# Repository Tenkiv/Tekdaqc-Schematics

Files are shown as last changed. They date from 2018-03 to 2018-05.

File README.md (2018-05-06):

# TekdaqcSchematics

pcb file for RevE and RevF are incomplete
- all digital grounds are currently unconnected
#TODO ground plane

RevE contains the files for the current Tekdaqc version

RevF is a modified version of the current Tekdaqc
- GIP15 is moved from PC14 to PH5
- GPI4 is moved from PH0 to PH3
- Digital Output connection has been modified to include a pull down resistor

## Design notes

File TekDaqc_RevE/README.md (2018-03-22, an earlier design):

Folder contains all necessary files to open and make changes to the schematic and pcb files in KiCad

*.pro - project file

*.sch - schematic files

*.lib - contains the components used in the schematic 

*.kicad_pcb - pcb file

*.pretty - contains the files of the footprints used in the pcb file

*.kicad_mod - footprint of the components used in the pcb file

*.net - links the schematic files to the pcb files

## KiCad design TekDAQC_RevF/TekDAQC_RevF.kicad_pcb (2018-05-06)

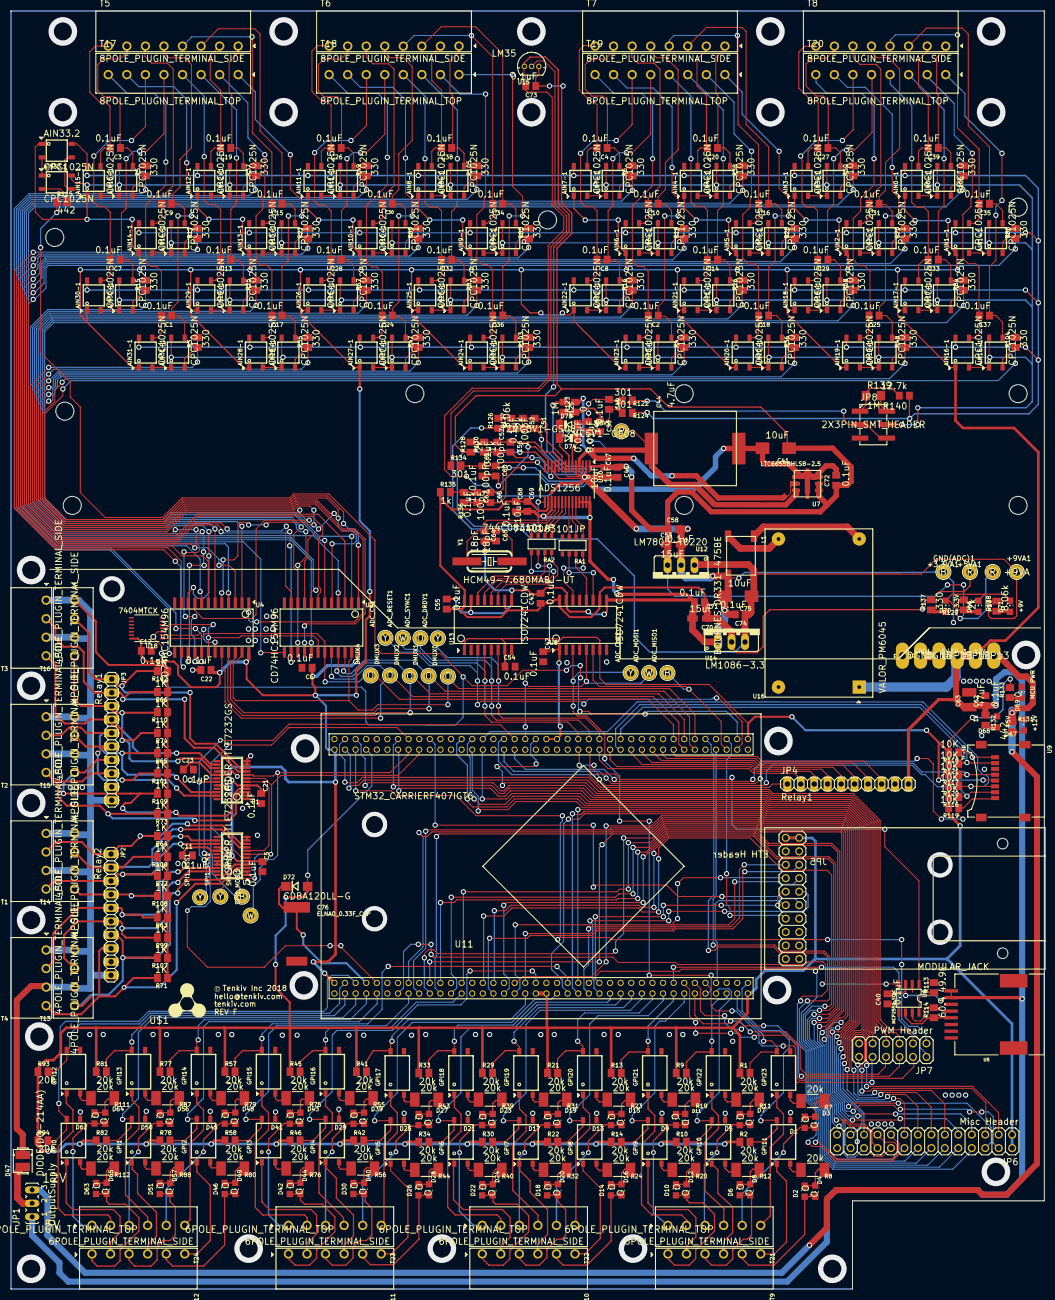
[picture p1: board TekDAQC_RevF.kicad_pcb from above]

Board: 2 copper layers, 194.9 x 241.1 mm, 441 parts (0 on the bottom side), 430 nets.

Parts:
2.5V1: R; OTHER_KEYSTONE_5000
5V, 5V-1, 12V: LSP13
+3.3VA1, +5VA1: R; OTHER_KEYSTONE_5000
+9VA1: +9VA; OTHER_KEYSTONE_5000
@HOLE0, @HOLE1, @HOLE2, @HOLE3, @HOLE4, @HOLE6, @HOLE7, @HOLE8, @HOLE9, @HOLE10: (no value)
@HOLE5: HOLE_CIRCLE
@HOLE11, @HOLE12, @HOLE13, @HOLE14: HOLE_OVAL
ADC_CLK1: Y; OTHER_KEYSTONE_5000
ADC_CS1: Y; OTHER_KEYSTONE_5000
ADC_DRDY1: Y; OTHER_KEYSTONE_5000
ADC_MISO1: B; OTHER_KEYSTONE_5000
ADC_MOSI1: W; OTHER_KEYSTONE_5000
ADC_RESET1: W; OTHER_KEYSTONE_5000
ADC_SYNC1: O; OTHER_KEYSTONE_5000
AIN0+1, AIN0-1, AIN1+1, AIN1-1, AIN2+1, AIN2-1, AIN3+1, AIN3-1, AIN4+1, AIN4-1, AIN5+1, AIN5-1, AIN6+1, AIN6-1, AIN7+1, AIN7-1, AIN8+1, AIN8-1, AIN9+1, AIN9-1, AIN10+1, AIN10-1, AIN11+1, AIN11-1, AIN12+1, AIN12-1, AIN13+1, AIN13-1, AIN14+1, AIN14-1, AIN15+1, AIN15-1, AIN16+1, AIN16-1, AIN17+1, AIN17-1, AIN18+1, AIN18-1, AIN19+1, AIN19-1, AIN20+1, AIN20-1, AIN21+1, AIN21-1, AIN22+1, AIN22-1, AIN23+1, AIN23-1, AIN24+1, AIN24-1, AIN25+1, AIN25-1, AIN26+1, AIN26-1, AIN27+1, AIN27-1, AIN28+1, AIN28-1, AIN29+1, AIN29-1, AIN30+1, AIN30-1, AIN31+1, AIN31-1, AIN33.1, AIN33.2: CPC1025N; CPC1025N_SOP4
C1, C2, C3, C4, C5, C6, C7, C8, C9, C10, C11, C12, C13, C14, C15, C16, C17, C18, C19, C20, C21, C22, C23, C24, C25, C26, C27, C28, C29, C30, C31, C32, C33, C34, C35, C36, C37, C38, C39, C40, C42, C43, C46, C49, C52, C54, C55, C57, C58, C61, C62, C67, C68, C71, C72, C73, C74: 0.1uF; CAPACITOR_C0805
C41, C75: 10uF; CAPACITOR_CT6032
C44: 4.7uF; CAPACITOR_6054
C47, C69: 10uF; CAPACITOR_C0805
C48, C50: 0.01uF; CAPACITOR_C0805
C51, C56, C60, C66: 100pF; CAPACITOR_C0805
C53, C70: 15uF; CAPACITOR_CT3216
C63: 47uF; CAPACITOR_C1210
C64, C65: 18pF; CAPACITOR_C0805
C76: ELNA0_0.33F_CAP; COIN_CELL_CAP
D1, D2, D3, D4, D5, D6, D7, D8, D9, D10, D11, D12, D13, D14, D15, D16, D17, D18, D19, D20, D21, D22, D23, D24, D25, D26, D27, D28, D29, D30, D39, D40, D41, D42, D43, D44, D45, D46, D48, D49, D50, D51, D56, D57, D62, D63, D64, D65: O; LED_CHIPLED_0805
D47: DIODE(DO-214AA); DO−214AA
D66: +5V; LED_CHIPLED_0805
D67: +12V; CHIPLED_0805
D68: +5V; CHIPLED_0805
D69: MCU PWR; LED_CHIPLED_0805
D70: +3.3V; LED_CHIPLED_0805
D71: +9V; LED_CHIPLED_0805
D72: CDBA120LL-G; DIODE_DO214AC(SMA)
D73, D74: TZMC5V1-GS08; SOD80C
DMUX0, DMUX1, DMUX2, DMUX3, DMUX4: O; OTHER_KEYSTONE_5000
DRILEGEND: DRILEGEND
GND1: DGND; LSP13
GND(ADC)1: B; OTHER_KEYSTONE_5000
GPI0, GPI1, GPI2, GPI3, GPI4, GPI5, GPI6, GPI7, GPI8, GPI9, GPI10, GPI11, GPI12, GPI13, GPI14, GPI15, GPI16, GPI17, GPI18, GPI19, GPI20, GPI21, GPI22, GPI23: PS2505l_4-SMD
JP1: OutputSupply; JUMPER_JP2
JP2: Relay2; PINHEAD_1X10
JP3, JP4: Relay1; PINHEAD_1X10
JP5: ETH Header; TEKDAQC_ETH_2X10
JP6: Misc Header; PINHEAD_2X14
JP7: PWM Header; TEKDAQC_2X06
JP8: 2X3PIN_SMT_HEADER; HEADER_2X3SMT_HEADER
L1: BOURNES_DR331-475BE; DR331_CHOKE
R1, R2, R9, R10, R13, R14, R21, R22, R29, R30, R33, R34, R41, R42, R45, R46, R57, R58, R77, R78, R81, R82, R93, R94: 20k; RESISTOR_M0805
R3, R4, R5, R6, R15, R16, R17, R18, R25, R26, R27, R28, R35, R36, R37, R38, R47, R48, R49, R50, R67, R68, R69, R70, R83, R84, R85, R86, R103, R104, R105, R106, R137: 330; RESISTOR_M0805
R7, R8, R11, R12, R19, R20, R23, R24, R31, R32, R39, R40, R43, R44, R55, R56, R75, R76, R79, R80, R87, R88, R111, R112: 20k; RESISTOR_R2010
R63, R64, R65, R66, R71, R72, R73, R74, R99, R100, R101, R102, R107, R108, R109, R110: 1K; RESISTOR_M0805
R113: 49.9k; RESISTOR_M0805
R114: 60.4; RESISTOR_M0805
R115, R131: 442; RESISTOR_M0805
R116, R117, R118, R119, R120, R121: 10K; RESISTOR_M0805
R122, R124, R134: 301; RESISTOR_M0805
R123, R133: 0; RESISTOR_M0805
R125: 1M; RESISTOR_M0805
R126, R138: 8.06k; RESISTOR_M0805
R127, R128, R129: 2k; RESISTOR_M0805
R130, R132, R135, R136: 1k; RESISTOR_M0805
R139: 1M; RESISTOR_R1206
R140: 12.7k; RESISTOR_R0805
RA1, RA2: 744C083101JP; TEKDAQC_5131_744SERIES
SPI1_MISO1: B; OTHER_KEYSTONE_5000
SPI1_MOSI1: W; OTHER_KEYSTONE_5000
SPI1_NSS1, SPI1_SCK1: Y; OTHER_KEYSTONE_5000
T1, T2, T3, T4: 4POLE_PLUGIN_TERMINAL_SIDE; TEKDAQC_4POLE_3.5MM_TERMINAL_SIDE
T5, T6, T7, T8: 8POLE_PLUGIN_TERMINAL_SIDE; TEKDAQC_8POLE_3.5MM_TERMINAL_SIDE
T9, T10, T11, T12: 6POLE_PLUGIN_TERMINAL_SIDE; TEKDAQC_6POLE_3.5MM_TERMINAL_SIDE
T13, T14, T15, T16: 4POLE_PLUGIN_TERMINAL_SIDE; TEKDAQC_4POLE_3.5MM_TERMINAL_TOP
T17, T18, T19, T20: 8POLE_PLUGIN_TERMINAL_TOP; TEKDAQC_8POLE_3.5MM_TERMINAL_TOP
T21, T22, T23, T24: 6POLE_PLUGIN_TERMINAL_TOP; TEKDAQC_6POLE_3.5MM_TERMINAL_TOP
U1, U3: SPIDER-TLE7232GS; SPIDER_TLE7232GS_SSOP24
U2, U4: CD74HC154M96; CD74HC154M96_SOIC24
U5: MODULAR_JACK; MODULAR_JACK44144
U6: MCP2551_SOIC
U7: LTC6655BHLS8-2.5; LTC6655LS8_CLCC8
U8, U13: ISO7241CDW; ISO7241CDW_SOIC16
U9: TF-SD
U10: ADS1256; ADS1256_SSOP28
U11: STM32_CARRIERF407IGT6; STM32_CARRIER
U12: LM7805-T0220; V_REG_78XXS
U14: LM1086-3.3; V_REG_317TS
U15: LM35; LM35_TO_92
U16: VALOR_PM6045; DIL24_4PIN
U18: 7404MTCX; 7404MTCX_TSSOP14
U$1: TENKIV_INFO_BLOCK
Y1: HCM49-7.680MABJ-UT; CRYSTAL_HCM49

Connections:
2.5REF: 2.5V1.TP, C44.1, R123.2, U7.P$6, U7.P$7, U10.4
+5V: 5V.MP, 5V-1.MP, AIN0-1.1, AIN1-1.1, AIN2-1.1, AIN3-1.1, AIN4-1.1, AIN5-1.1, AIN6-1.1, AIN7-1.1, AIN8-1.1, AIN9-1.1, AIN10-1.1, AIN11-1.1, AIN12-1.1, AIN13-1.1, AIN14-1.1, AIN15-1.1, AIN16-1.1, AIN17-1.1, AIN18-1.1, AIN19-1.1, AIN20-1.1, AIN21-1.1, AIN22-1.1, AIN23-1.1, AIN24-1.1, AIN25-1.1, AIN26-1.1, AIN27-1.1, AIN28-1.1, AIN29-1.1, AIN30-1.1, AIN31-1.1, AIN33.2.1, C5.1, C6.1, C11.1, C12.1, C21.1, C22.1, C23.1, C40.2, C62.1, C63.1, JP1.1, JP4.10, R132.1, U1.5, U1.17, U2.24, U3.5, U3.17, U4.24, U5.1, U5.2, U6.3, U11.5V-I, U16.1, U18.14
+5V/1: +5VA1.TP, C41.+, C46.1, C47.1, C53.+, C58.1, C72.1, C73.1, R128.1, R129.2, U7.P$1, U7.P$2, U10.1, U12.OUT, U15.1
+9V: +9VA1.TP, C74.1, C75.+, L1.P$4, R126.1, R138.2, U12.IN, U14.3
+12V: 12V.MP, JP1.3, R131.1
/N$1: D68.A, R132.2
/N$4: D67.A, R131.2
/N$17: D69.A, R133.1
/N$105: R114.2, U5.4, U6.7
/N$106: R114.1, U5.5, U6.6
/N$107: R113.1, U6.8
/TekDAQC_RevF_AD.sch/DOUT: RA1.P$6, U8.11
/TekDAQC_RevF_AD.sch/N$2: AIN33.1.2, R115.2
/TekDAQC_RevF_AD.sch/N$3: RA2.P$3, U10.15
/TekDAQC_RevF_AD.sch/N$5: AIN33.1.1, AIN33.2.2
/TekDAQC_RevF_AD.sch/N$12: R134.1, U15.2
/TekDAQC_RevF_AD.sch/N$15: C48.1, C49.1, D73.A, D74.C, R122.2, U10.6
/TekDAQC_RevF_AD.sch/N$16: C49.2, C50.1, D73.C, D74.A, R123.1, R124.2, R125.2, U10.7
/TekDAQC_RevF_AD.sch/N$20: C65.1, U10.19, Y1.P$1
/TekDAQC_RevF_AD.sch/N$21: C64.1, U10.18, Y1.P$2
/TekDAQC_RevF_AD.sch/N$23: RA1.P$2, U10.23
/TekDAQC_RevF_AD.sch/N$24: RA1.P$1, U10.24
/TekDAQC_RevF_AD.sch/N$28: D70.A, R137.1
/TekDAQC_RevF_AD.sch/N$29: RA1.P$8, U8.14
/TekDAQC_RevF_AD.sch/N$30: RA1.P$7, U8.12
/TekDAQC_RevF_AD.sch/N$108: RA2.P$2, U10.20
/TekDAQC_RevF_AD.sch/N$110: AIN33.1.3, AIN33.2.3
/TekDAQC_RevF_AD.sch/N$114: L1.P$1, U16.12
/TekDAQC_RevF_AD.sch/N$116: JP8.P$2, JP8.P$4, R122.1
/TekDAQC_RevF_AD.sch/N$117: L1.P$2, U16.13
/TekDAQC_RevF_AD.sch/N$124: JP8.P$6, R139.2
/TekDAQC_RevF_AD.sch/N$125: JP8.P$1, R139.1, R140.2
/TekDAQC_RevF_AD.sch/N$149: RA2.P$1, U10.21
/TekDAQC_RevF_AD.sch/N$152: RA2.P$4, U10.14
/TekDAQC_RevF_AD.sch/N$153: RA2.P$8, U13.11
/TekDAQC_RevF_AD.sch/N$154: RA2.P$5, U13.12
/TekDAQC_RevF_AD.sch/N$155: RA2.P$6, U13.13
/TekDAQC_RevF_AD.sch/N$156: RA2.P$7, U13.14
/TekDAQC_RevF_AD.sch/N$160: C51.1, C52.1, R126.2, R127.2, U10.9
/TekDAQC_RevF_AD.sch/N$161: RA1.P$3, U10.22
/TekDAQC_RevF_AD.sch/N$162: D71.A, R138.1
/TekDAQC_RevF_AD.sch/N$163: D66.A, R129.1
/TekDAQC_RevF_AD.sch/N$164: C66.1, C67.1, R135.2, R136.2, U10.13
/TekDAQC_RevF_AD.sch/N$165: C60.1, C61.1, R134.2, U10.12
/TekDAQC_RevF_AD.sch/N$166: C56.1, C57.1, R128.2, R130.2, U10.10
/TekDAQC_RevF_AI/N$18: AIN0+1.2, R106.2
/TekDAQC_RevF_AI/N$19: AIN1+1.2, R86.2
/TekDAQC_RevF_AI/N$22: AIN0+1.1, AIN0-1.2
/TekDAQC_RevF_AI/N$31: AIN24+1.1, AIN24-1.2
/TekDAQC_RevF_AI/N$33: AIN24+1.2, R103.2
/TekDAQC_RevF_AI/N$34: AIN1+1.1, AIN1-1.2
/TekDAQC_RevF_AI/N$35: AIN2+1.1, AIN2-1.2
/TekDAQC_RevF_AI/N$36: AIN2+1.2, R70.2
/TekDAQC_RevF_AI/N$37: AIN3+1.2, R50.2
/TekDAQC_RevF_AI/N$38: AIN3+1.1, AIN3-1.2
/TekDAQC_RevF_AI/N$39: AIN4+1.1, AIN4-1.2
/TekDAQC_RevF_AI/N$40: AIN4+1.2, R38.2
/TekDAQC_RevF_AI/N$41: AIN5+1.2, R28.2
/TekDAQC_RevF_AI/N$42: AIN6+1.2, R18.2
/TekDAQC_RevF_AI/N$43: AIN5+1.1, AIN5-1.2
/TekDAQC_RevF_AI/N$44: AIN6+1.1, AIN6-1.2
/TekDAQC_RevF_AI/N$45: AIN7+1.1, AIN7-1.2
/TekDAQC_RevF_AI/N$46: AIN7+1.2, R6.2
/TekDAQC_RevF_AI/N$47: AIN8+1.2, R105.2
/TekDAQC_RevF_AI/N$48: AIN8+1.1, AIN8-1.2
/TekDAQC_RevF_AI/N$49: AIN9+1.1, AIN9-1.2
/TekDAQC_RevF_AI/N$50: AIN9+1.2, R85.2
/TekDAQC_RevF_AI/N$51: AIN10+1.2, R69.2
/TekDAQC_RevF_AI/N$52: AIN10+1.1, AIN10-1.2
/TekDAQC_RevF_AI/N$53: AIN11+1.1, AIN11-1.2
/TekDAQC_RevF_AI/N$54: AIN11+1.2, R49.2
/TekDAQC_RevF_AI/N$55: AIN12+1.1, AIN12-1.2
/TekDAQC_RevF_AI/N$56: AIN12+1.2, R37.2
/TekDAQC_RevF_AI/N$57: AIN13+1.1, AIN13-1.2
/TekDAQC_RevF_AI/N$58: AIN13+1.2, R27.2
/TekDAQC_RevF_AI/N$59: AIN14+1.1, AIN14-1.2
/TekDAQC_RevF_AI/N$60: AIN14+1.2, R17.2
/TekDAQC_RevF_AI/N$61: AIN15+1.1, AIN15-1.2
/TekDAQC_RevF_AI/N$62: AIN15+1.2, R5.2
/TekDAQC_RevF_AI/N$63: AIN25+1.2, R83.2
/TekDAQC_RevF_AI/N$64: AIN25+1.1, AIN25-1.2
/TekDAQC_RevF_AI/N$65: AIN26+1.1, AIN26-1.2
/TekDAQC_RevF_AI/N$66: AIN26+1.2, R67.2
/TekDAQC_RevF_AI/N$67: AIN27+1.1, AIN27-1.2
/TekDAQC_RevF_AI/N$68: AIN27+1.2, R47.2
/TekDAQC_RevF_AI/N$69: AIN28+1.1, AIN28-1.2
/TekDAQC_RevF_AI/N$70: AIN28+1.2, R35.2
/TekDAQC_RevF_AI/N$71: AIN29+1.1, AIN29-1.2
/TekDAQC_RevF_AI/N$72: AIN29+1.2, R25.2
/TekDAQC_RevF_AI/N$73: AIN30+1.1, AIN30-1.2
/TekDAQC_RevF_AI/N$74: AIN30+1.2, R15.2
/TekDAQC_RevF_AI/N$75: AIN31+1.1, AIN31-1.2
/TekDAQC_RevF_AI/N$76: AIN31+1.2, R3.2
/TekDAQC_RevF_AI/N$78: AIN16+1.2, R104.2
/TekDAQC_RevF_AI/N$79: AIN17+1.2, R84.2
/TekDAQC_RevF_AI/N$80: AIN18+1.2, R68.2
/TekDAQC_RevF_AI/N$81: AIN19+1.2, R48.2
/TekDAQC_RevF_AI/N$83: AIN20+1.2, R36.2
/TekDAQC_RevF_AI/N$84: AIN21+1.2, R26.2
/TekDAQC_RevF_AI/N$85: AIN22+1.2, R16.2
/TekDAQC_RevF_AI/N$86: AIN23+1.2, R4.2
/TekDAQC_RevF_AI/N$87: AIN16+1.1, AIN16-1.2
/TekDAQC_RevF_AI/N$88: AIN17+1.1, AIN17-1.2
/TekDAQC_RevF_AI/N$89: AIN18+1.1, AIN18-1.2
/TekDAQC_RevF_AI/N$90: AIN19+1.1, AIN19-1.2
/TekDAQC_RevF_AI/N$91: AIN20+1.1, AIN20-1.2
/TekDAQC_RevF_AI/N$92: AIN21+1.1, AIN21-1.2
/TekDAQC_RevF_AI/N$93: AIN22+1.1, AIN22-1.2
/TekDAQC_RevF_AI/N$94: AIN23+1.1, AIN23-1.2
/TekDAQC_RevF_DI.sch/N$186: GPI1.2, R88.2
/TekDAQC_RevF_DI.sch/N$187: GPI2.2, R80.2
/TekDAQC_RevF_DI.sch/N$188: GPI3.2, R76.2
/TekDAQC_RevF_DI.sch/N$189: GPI4.2, R56.2
/TekDAQC_RevF_DI.sch/N$190: GPI5.2, R44.2
/TekDAQC_RevF_DI.sch/N$191: GPI6.2, R40.2
/TekDAQC_RevF_DI.sch/N$192: GPI7.2, R32.2
/TekDAQC_RevF_DI.sch/N$193: GPI8.2, R24.2
/TekDAQC_RevF_DI.sch/N$194: GPI9.2, R20.2
/TekDAQC_RevF_DI.sch/N$195: GPI10.2, R12.2
/TekDAQC_RevF_DI.sch/N$196: GPI11.2, R8.2
/TekDAQC_RevF_DI.sch/N$197: GPI12.2, R111.2
/TekDAQC_RevF_DI.sch/N$198: GPI13.2, R87.2
/TekDAQC_RevF_DI.sch/N$199: GPI14.2, R79.2
/TekDAQC_RevF_DI.sch/N$200: GPI15.2, R75.2
/TekDAQC_RevF_DI.sch/N$201: GPI16.2, R55.2
/TekDAQC_RevF_DI.sch/N$202: GPI17.2, R43.2
/TekDAQC_RevF_DI.sch/N$203: GPI18.2, R39.2
/TekDAQC_RevF_DI.sch/N$204: GPI19.2, R31.2
/TekDAQC_RevF_DI.sch/N$205: GPI20.2, R23.2
/TekDAQC_RevF_DI.sch/N$206: GPI21.2, R19.2
/TekDAQC_RevF_DI.sch/N$207: GPI22.2, R11.2
/TekDAQC_RevF_DI.sch/N$208: GPI23.2, R7.2
/TekDAQC_RevF_DI.sch/N$209: GPI0.2, R112.2
/TekDAQC_RevF_DI.sch/N$211: D63.C, D65.A, R112.1
/TekDAQC_RevF_DI.sch/N$212: D51.C, D57.A, R88.1
/TekDAQC_RevF_DI.sch/N$213: D46.C, D49.A, R80.1
/TekDAQC_RevF_DI.sch/N$214: D42.C, D44.A, R76.1
/TekDAQC_RevF_DI.sch/N$215: D30.C, D40.A, R56.1
/TekDAQC_RevF_DI.sch/N$216: D26.C, D28.A, R44.1
/TekDAQC_RevF_DI.sch/N$217: D22.C, D24.A, R40.1
/TekDAQC_RevF_DI.sch/N$218: D18.C, D20.A, R32.1
/TekDAQC_RevF_DI.sch/N$219: D14.C, D16.A, R24.1
/TekDAQC_RevF_DI.sch/N$220: D10.C, D12.A, R20.1
/TekDAQC_RevF_DI.sch/N$221: D6.C, D8.A, R12.1
/TekDAQC_RevF_DI.sch/N$222: D2.C, D4.A, R8.1
/TekDAQC_RevF_DI.sch/N$223: D62.C, D64.A, R111.1
/TekDAQC_RevF_DI.sch/N$224: D50.C, D56.A, R87.1
/TekDAQC_RevF_DI.sch/N$225: D45.C, D48.A, R79.1
/TekDAQC_RevF_DI.sch/N$226: D41.C, D43.A, R75.1
/TekDAQC_RevF_DI.sch/N$227: D29.C, D39.A, R55.1
/TekDAQC_RevF_DI.sch/N$228: D25.C, D27.A, R43.1
/TekDAQC_RevF_DI.sch/N$229: D21.C, D23.A, R39.1
/TekDAQC_RevF_DI.sch/N$230: D17.C, D19.A, R31.1
/TekDAQC_RevF_DI.sch/N$231: D13.C, D15.A, R23.1
/TekDAQC_RevF_DI.sch/N$232: D9.C, D11.A, R19.1
/TekDAQC_RevF_DI.sch/N$233: D5.C, D7.A, R11.1
/TekDAQC_RevF_DI.sch/N$234: D1.C, D3.A, R7.1
/TekDAQC_RevF_DO.sch//DMUX4: U4.19, U18.2
/TekDAQC_RevF_DO.sch/N$77: D47.2, JP2.10, JP3.10, R63.1, R64.1, R65.1, R66.1, R71.1, R72.1, R73.1, R74.1, R99.1, R100.1, R101.1, R102.1, R107.1, R108.1, R109.1, R110.1, T1.1, T1.3, T2.1, T2.3, T3.1, T3.3, T4.1, T4.3, T13.1, T13.3, T14.1, T14.3, T15.1, T15.3, T16.1, T16.3
/TekDAQC_RevF_DO.sch/N$82: U1.6, U3.8
/TekDAQC_RevF_DO.sch/N$118: D47.1, JP1.2
/TekDAQC_RevF_DO.sch/OCAL_: U2.18, U4.18, U18.4
/VBAT: C76.P$1, D72.C, U11.VBAT
ADC1_IN0: JP6.4, U11.PA0
ADC1_IN3: JP6.6, U11.PA3
ADC1_IN6: JP6.8, U11.PA6
ADC2_IN10: JP6.10, U11.PC0
ADC2_IN12: JP6.12, U11.PC2
ADC2_IN13: JP6.14, U11.PC3
ADC3_IN4: JP6.16, U11.PF6
ADC3_IN5: JP6.18, U11.PF7
ADC3_IN8: JP6.20, U11.PF10
ADC3_IN9: JP6.22, U11.PF3
ADC3_IN14: JP6.24, U11.PF4
ADC3_IN15: JP6.26, U11.PF5
AIN0: AIN0+1.4, AIN1+1.4, AIN2+1.4, AIN3+1.4, AIN4+1.4, AIN5+1.4, AIN6+1.4, AIN7+1.4, AIN8+1.4, AIN9+1.4, AIN10+1.4, AIN11+1.4, AIN12+1.4, AIN13+1.4, AIN14+1.4, AIN15+1.4, AIN16+1.4, AIN17+1.4, AIN18+1.4, AIN19+1.4, AIN20+1.4, AIN21+1.4, AIN22+1.4, AIN23+1.4, AIN24+1.4, AIN25+1.4, AIN26+1.4, AIN27+1.4, AIN28+1.4, AIN29+1.4, AIN30+1.4, AIN31+1.4, AIN33.1.4, JP8.P$5
AIN1: AIN0-1.4, AIN1-1.4, AIN2-1.4, AIN3-1.4, AIN4-1.4, AIN5-1.4, AIN6-1.4, AIN7-1.4, AIN8-1.4, AIN9-1.4, AIN10-1.4, AIN11-1.4, AIN12-1.4, AIN13-1.4, AIN14-1.4, AIN15-1.4, AIN16-1.4, AIN17-1.4, AIN18-1.4, AIN19-1.4, AIN20-1.4, AIN21-1.4, AIN22-1.4, AIN23-1.4, AIN24-1.4, AIN25-1.4, AIN26-1.4, AIN27-1.4, AIN28-1.4, AIN29-1.4, AIN30-1.4, AIN31-1.4, AIN33.2.4, R124.1, R140.1
CAN1_RX: U6.4, U11.PI9
CAN1_TX: U6.1, U11.PH13
DAC_OUT1: JP6.23, U11.PA4
DAC_OUT2: JP6.25, U11.PA5
DGND: C5.2, C6.2, C11.2, C12.2, C21.2, C22.2, C23.2, C40.1, C42.2, C54.2, C62.2, C63.2, C76.P$2, D67.C, D68.C, D69.C, GND1.MP, GPI0.3, GPI1.3, GPI2.3, GPI3.3, GPI4.3, GPI5.3, GPI6.3, GPI7.3, GPI8.3, GPI9.3, GPI10.3, GPI11.3, GPI12.3, GPI13.3, GPI14.3, GPI15.3, GPI16.3, GPI17.3, GPI18.3, GPI19.3, GPI20.3, GPI21.3, GPI22.3, GPI23.3, JP2.9, JP3.9, JP4.9, JP5.3, JP5.4, JP6.27, JP6.28, JP7.11, JP7.12, R113.2, U1.1, U1.2, U1.11, U1.12, U1.16, U1.20, U1.21, U2.12, U3.1, U3.2, U3.11, U3.12, U3.16, U3.20, U3.21, U4.12, U5.3, U5.6, U5.7, U5.8, U5.G1, U5.G2, U6.2, U8.2, U8.8, U9.G1, U9.G2, U9.G3, U9.G4, U9.PIN6, U11.GND-, U13.2, U13.8, U16.24, U18.5, U18.7, U18.9, U18.11, U18.13
DMUX0: DMUX0.TP, U2.23, U4.23, U11.PD11
DMUX1: DMUX1.TP, U2.22, U4.22, U11.PD12
DMUX2: DMUX2.TP, U2.21, U4.21, U11.PD13
DMUX3: DMUX3.TP, U2.20, U4.20, U11.PD14
DMUX4: DMUX4.TP, U2.19, U11.PD15, U18.1
ETH_RMII_CRS_DV: JP5.8, U11.PA7
ETH_RMII_MDC: JP5.6, U11.PC1
ETH_RMII_MDIO: JP5.5, U11.PA2
ETH_RMII_REF_CLK: JP5.7, U11.PA1
ETH_RMII_RXD0: JP5.9, U11.PC4
ETH_RMII_RXD1: JP5.10, U11.PC5
ETH_RMII_TXD0: JP5.12, U11.PG13
ETH_RMII_TXD1: JP5.13, U11.PB13
ETH_RMII_TX_EN: JP5.11, U11.PB11
GND: C41.-, C43.2, C44.2, C46.2, C47.2, C48.2, C50.2, C51.2, C52.2, C53.-, C55.2, C56.2, C57.2, C58.2, C60.2, C61.2, C64.2, C65.2, C66.2, C67.2, C68.2, C69.2, C70.-, C71.2, C72.2, C73.2, C74.2, C75.-, D66.C, D70.C, D71.C, GND(ADC)1.TP, L1.P$3, R125.1, R127.1, R130.1, R136.1, U7.P$3, U7.P$4, U7.P$5, U7.P$8, U8.9, U8.15, U10.2, U10.3, U10.5, U10.8, U10.11, U10.17, U10.25, U10.26, U10.27, U10.28, U12.GND, U13.9, U13.15, U14.1, U15.3
GPI0: GPI0.4, R94.2, U11.PE5
GPI0+: GPI0.1, T12.2
GPI0-: D63.A, D65.C, T12.1
GPI1: GPI1.4, R82.2, U11.PE4
GPI1+: GPI1.1, T12.4
GPI1-: D51.A, D57.C, T12.3
GPI2: GPI2.4, R78.2, U11.PI8
GPI2+: GPI2.1, T12.6
GPI2-: D46.A, D49.C, T12.5
GPI3: GPI3.4, R58.2, U11.PI11
GPI3+: GPI3.1, T11.2
GPI3-: D42.A, D44.C, T11.1
GPI4: GPI4.4, R46.2, U11.PH3
GPI4+: GPI4.1, T11.4
GPI4-: D30.A, D40.C, T11.3
GPI5: GPI5.4, R42.2, U11.PH4
GPI5+: GPI5.1, T11.6
GPI5-: D26.A, D28.C, T11.5
GPI6: GPI6.4, R34.2, U11.PF11
GPI6+: GPI6.1, T10.2
GPI6-: D22.A, D24.C, T10.1
GPI7: GPI7.4, R30.2, U11.PF15
GPI7+: GPI7.1, T10.4
GPI7-: D18.A, D20.C, T10.3
GPI8: GPI8.4, R22.2, U11.PE8
GPI8+: GPI8.1, T10.6
GPI8-: D14.A, D16.C, T10.5
GPI9: GPI9.4, R14.2, U11.PE12
GPI9+: GPI9.1, T9.2
GPI9-: D10.A, D12.C, T9.1
GPI10: GPI10.4, R10.2, U11.PH6
GPI10+: GPI10.1, T9.4
GPI10-: D6.A, D8.C, T9.3
GPI11: GPI11.4, R2.2, U11.PH11
GPI11+: GPI11.1, T9.6
GPI11-: D2.A, D4.C, T9.5
GPI12: GPI12.4, R93.2, U11.PE3
GPI12+: GPI12.1, T24.2
GPI12-: D62.A, D64.C, T24.1
GPI13: GPI13.4, R81.2, U11.PE2
GPI13+: GPI13.1, T24.4
GPI13-: D50.A, D56.C, T24.3
GPI14: GPI14.4, R77.2, U11.PE6
GPI14+: GPI14.1, T24.6
GPI14-: D45.A, D48.C, T24.5
GPI15: GPI15.4, R57.2, U11.PH5
GPI15+: GPI15.1, T23.2
GPI15-: D41.A, D43.C, T23.1
GPI16: GPI16.4, R45.2, U11.PF9
GPI16+: GPI16.1, T23.4
GPI16-: D29.A, D39.C, T23.3
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

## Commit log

2018-03-22 schematic/pcb/library files
    schematic files - '*.sch'
    pcb file - '*.brd'
    library - '*.lib'
    net - '*.net'
    [TekDAQC_RevC.brd, TekDAQC_RevE.kicad_pcb, TekDAQC_RevE.sch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]
2018-03-22 Footprints used on pcb board
2018-03-22 renamed: TekDaqc_RevE/TekDAQC_RevE.pretty/TekDAQC_RevE.pretty/7404MTCX_TSSOP14.kicad_mod -> TekDaqc_RevE/TekDAQC_RevE.pretty/7404MTCX_TSSOP14.kicad_mod renamed: TekDaqc_RevE/TekDAQC_RevE.pretty/TekDA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
2018-05-06 current tekdaqc unmodified
    [TekDAQC_RevC.brd, TekDAQC_RevE.kicad_pcb, TekDAQC_RevE.sch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]
2018-05-06 new file: TekDAQC_RevF/TekDAQC_RevF.kicad_pcb new file: TekDAQC_RevF/TekDAQC_RevF.lib new file: TekDAQC_RevF/TekDAQC_RevF.net new file: TekDAQC_RevF/TekDAQC_RevF.pretty/7404MTCX_TSSOP14.kicad_mod new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
    [TekDAQC_RevF.kicad_pcb, TekDAQC_RevF.sch, TekDAQC_RevF_AD.sch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]
